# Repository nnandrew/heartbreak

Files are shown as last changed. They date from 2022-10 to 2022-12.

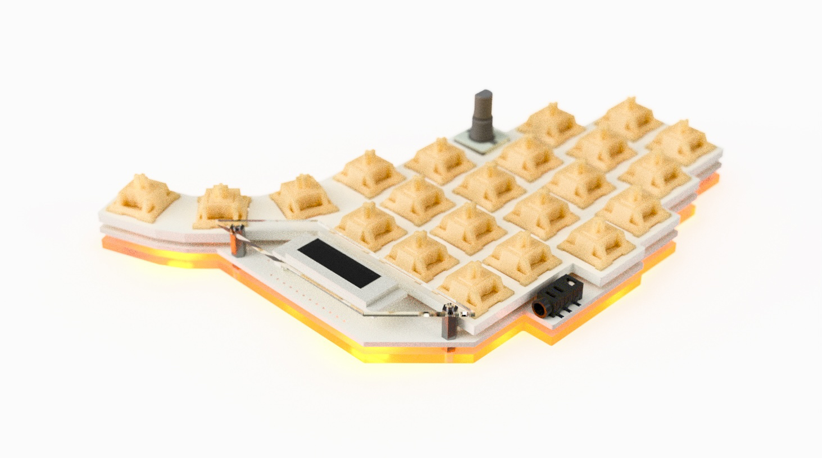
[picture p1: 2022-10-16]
CONCEPTS/underglow_render.jpg

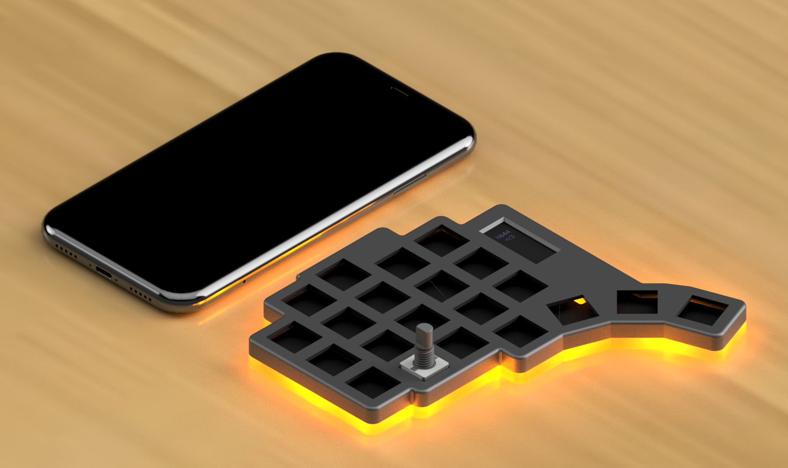
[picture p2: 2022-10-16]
CONCEPTS/aluminum case.png

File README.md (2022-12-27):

# heartbreak
a 40 Key Wireless BLE Split Keyboard with Encoders, LCDs, Haptic Feedback, Fingerprint Reading, Underglow, and a corny theme.

centerGlow
zoom

## Parts
### Required

| Name | Count | Notes |
|:-|:-|:-|
| PCB | 2 | Reversible |
| PCB Coin | 1-2 | fills case hole with a <3 |
| Top Shell | 2  | 3D printed or machined integrated plate |
| Bottom Shell | 2  | Transparent resin print |
| Magnets | 48  | 3x1mm to hold the case together |
| nice!nano v2.0 | 2 | ZMK BLE |
| MCU Sockets | 50-70 | 0627-0-15-15-21-27-10-0 | 
| MCU Pins | 50-70 | 3320-0-00-15-00-00-03-0 |
| Reset Switch | 2 | B3U-3000P-B |
| Power Switch | 2 | PCM12 |
| Battery | 2 | 301230 size |
| Diodes | 42 | SOD-123 SMD |
| Switch Sockets | 40 | Kailh sockets |
| Key Switches | 40 | Only compatible with MX style |
| Keycaps | 40 | All 1u |
| USB C cable | 1 | Data lines required for flashing |

### Optional

| Name | Count | Remarks |
|:-|:-|:-|
| Rubber feet | 8 | reduce sliding |
| nice!view LCD | 2 | low power draw |
| Pimoroni Haptic Buzz | 1 | requires custom firmware |
| Waveshare UART Fingerprint Sensor | 1 | requires custom firmware |
| EC11 Rotary Encoder | 2 | using hardware debouncing |
| 17mm Encoder Knob | 2 | a tight fit |
| Schmitt Trigger | 2 | 74AUP2G14 |
| 10kOhm Resistors | 8 | encoder debounce |
| 0.1uC Capacitors | 4 | for leds and debounce |
| WS2812B | 9 | LEDs for Undergrow |
| SK6812-SIDE | 4 | LEDs for Undergrow |
| P-Channel MOSFET | 2 | SOT-23 to shutoff LEDs |
| 200Ohm Resistors | 2 | current limit for mosfet |
| 200kOhm Resistors | 2 | pulldown for mosfet |
| 0.1uC Capacitors | 26 | for leds and debounce |

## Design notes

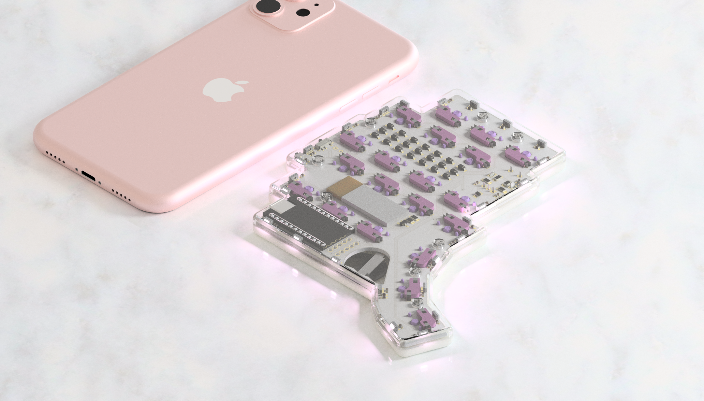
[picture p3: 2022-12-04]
CONCEPTS/showcase v4.png

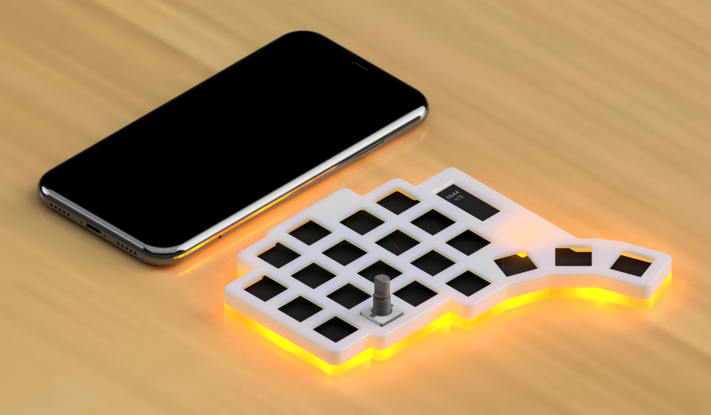
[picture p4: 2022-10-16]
CONCEPTS/plastic case.png

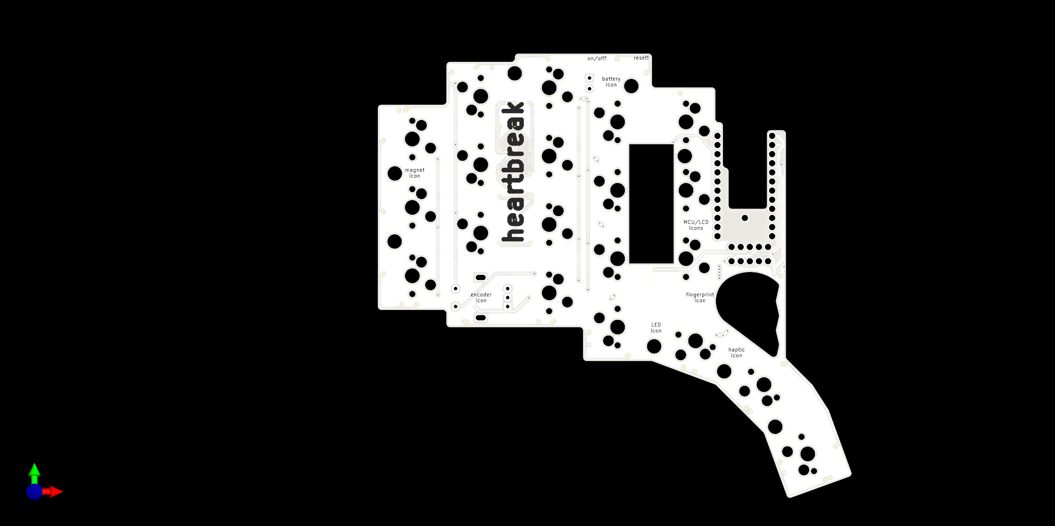
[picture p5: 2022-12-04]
CONCEPTS/frontPCB.png

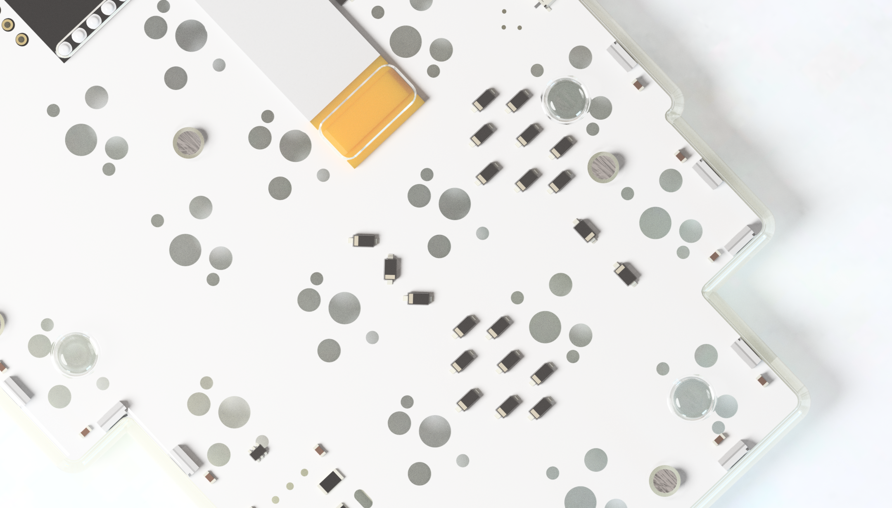
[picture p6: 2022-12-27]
CONCEPTS/heartDiodes.png

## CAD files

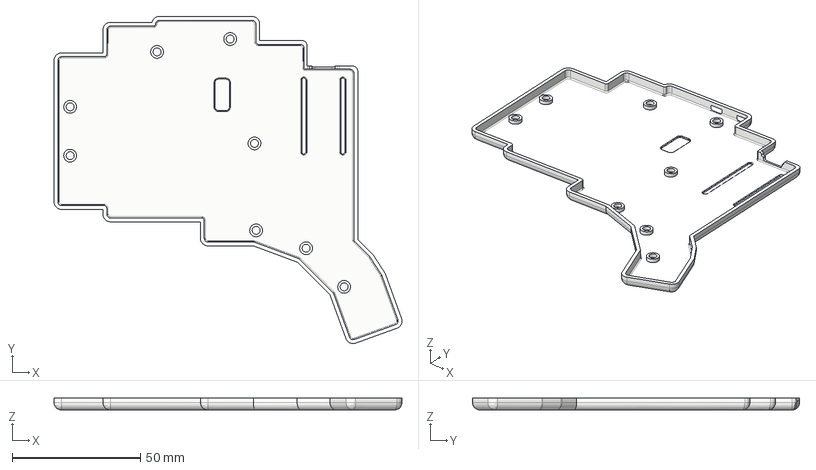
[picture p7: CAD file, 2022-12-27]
3D/production_bottomShell_L.step
135.9 x 127.7 x 4.70 mm

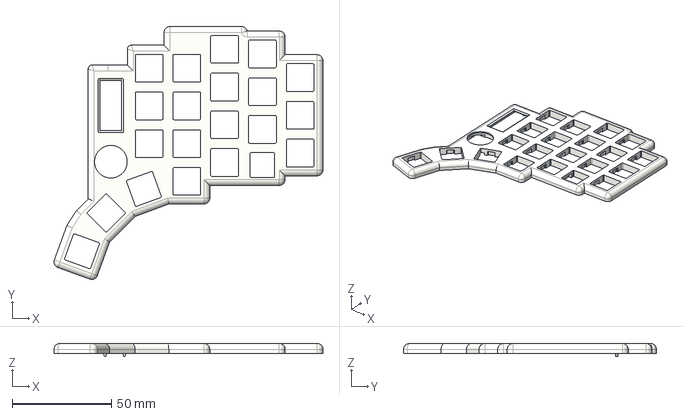
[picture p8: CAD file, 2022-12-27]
3D/production_topShellR.step
135.9 x 127.7 x 6.60 mm

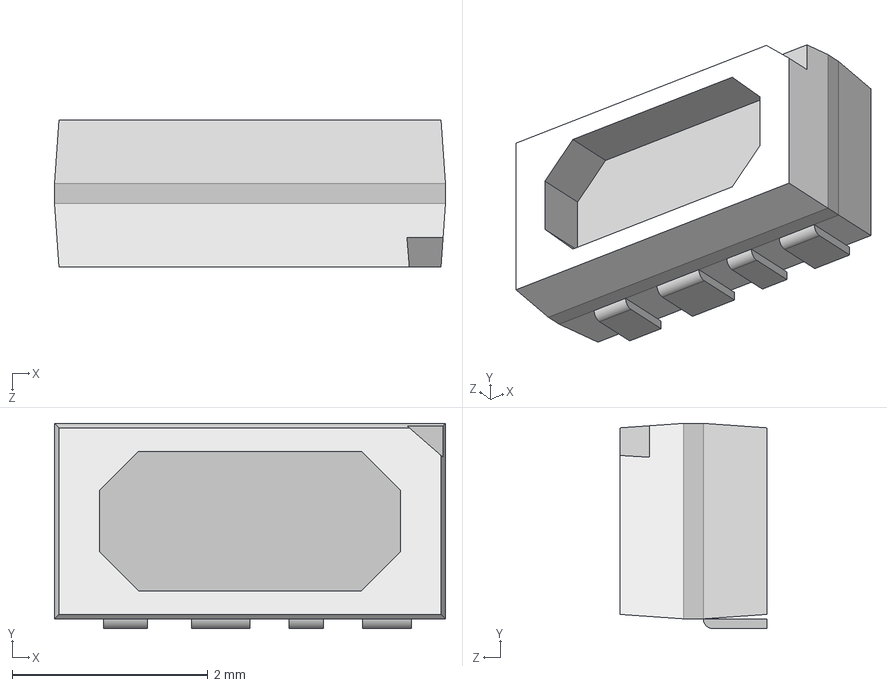
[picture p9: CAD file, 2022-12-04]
3D/SK6812_4020.step
4.00 x 2.10 x 1.50 mm

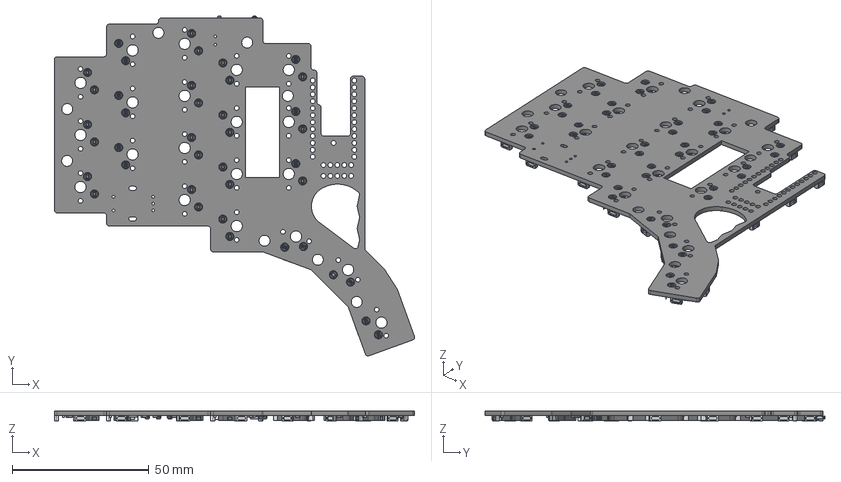
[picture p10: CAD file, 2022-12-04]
3D/pcb.step
131.8 x 124.4 x 3.65 mm
keyboard PCB

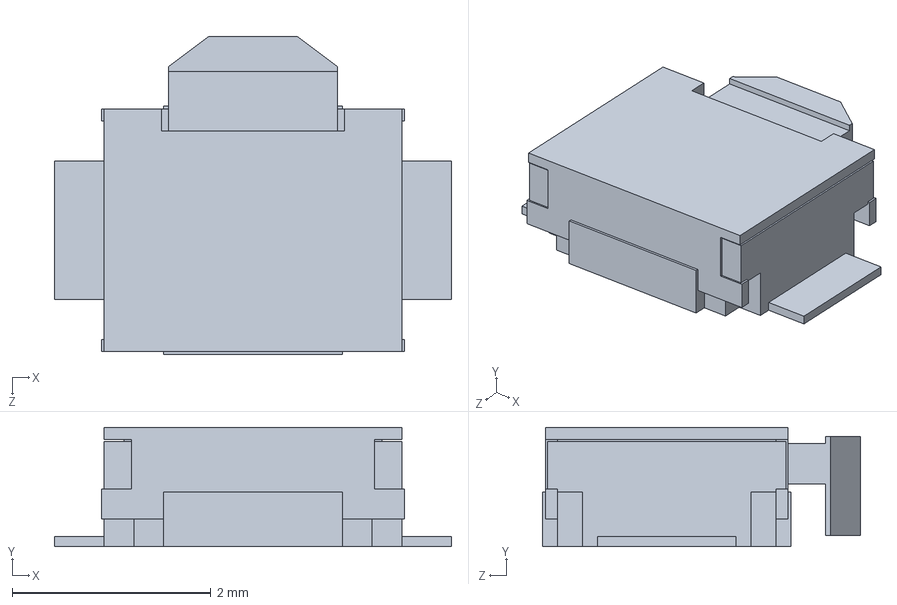
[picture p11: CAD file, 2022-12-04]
3D/B3U_3000P.step
4.00 x 1.20 x 3.20 mm

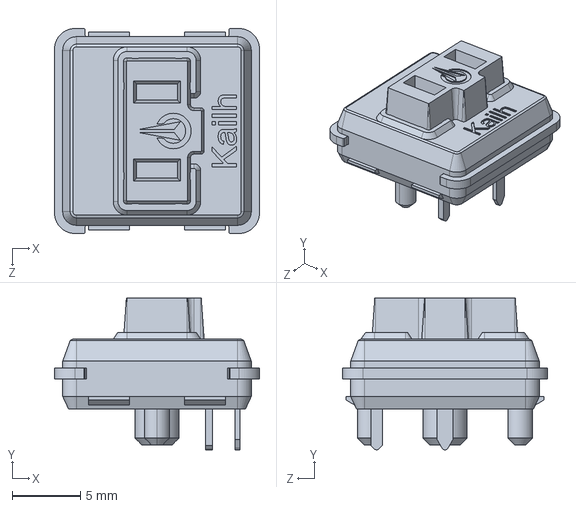
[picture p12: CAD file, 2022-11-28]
3D/Kailh LP Choc Burnt Orange.STEP
15.0 x 11.1 x 15.0 mm

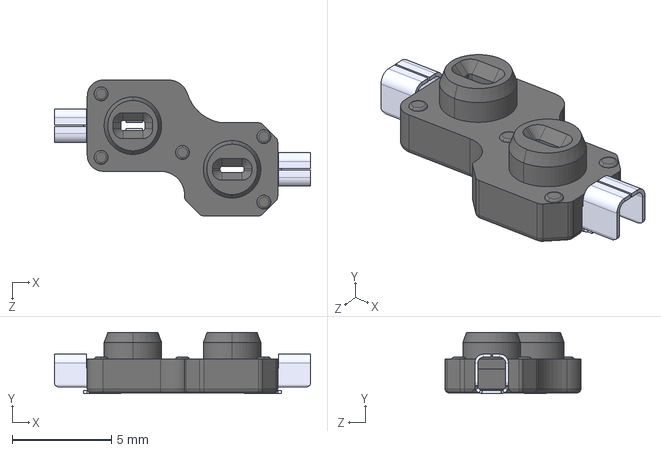
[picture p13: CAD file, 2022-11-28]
3D/PG1350-socket.STEP
12.9 x 3.09 x 6.85 mm
pin x 2
socket

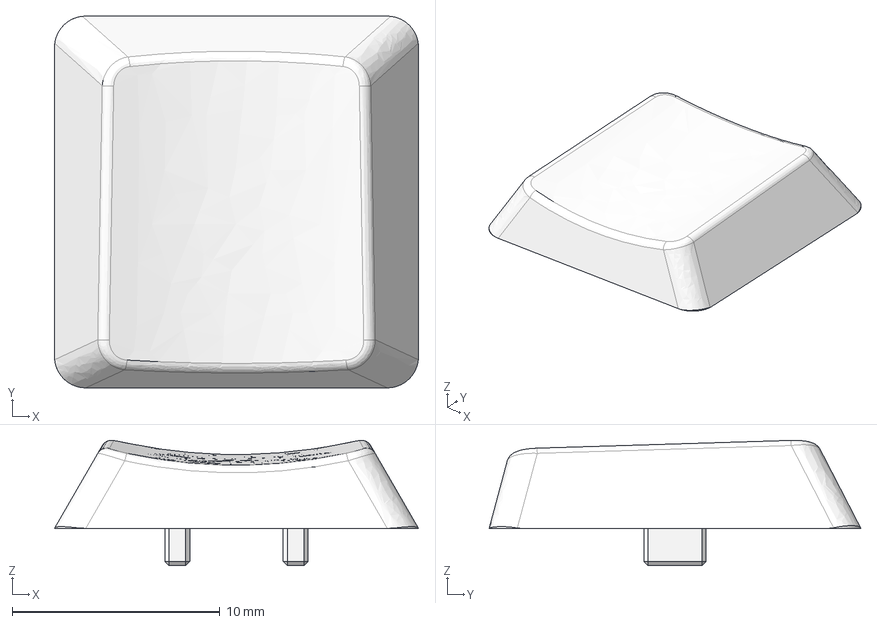
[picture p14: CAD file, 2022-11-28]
3D/Kailh LP Choc PC Keycap.step
17.5 x 17.9 x 6.03 mm

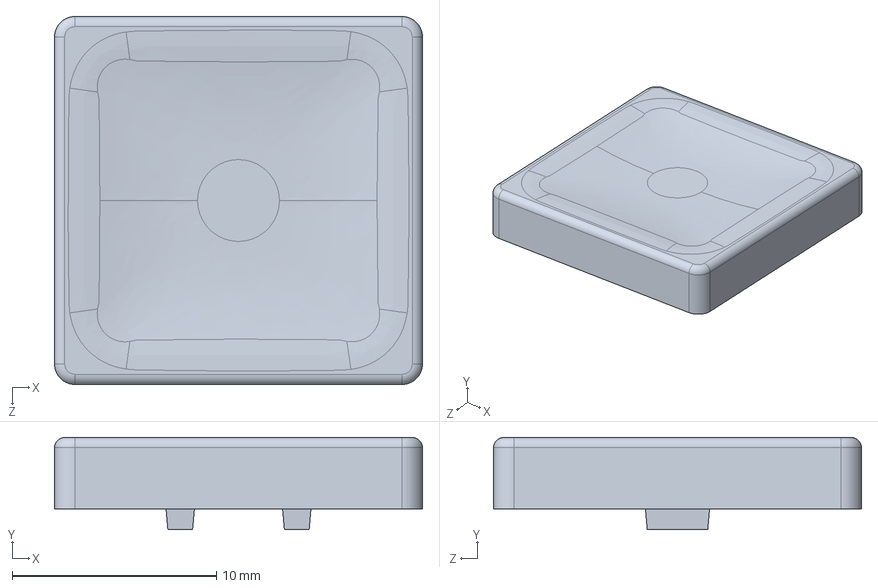
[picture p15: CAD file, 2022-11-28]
3D/1x1.STEP
18.0 x 4.50 x 18.0 mm

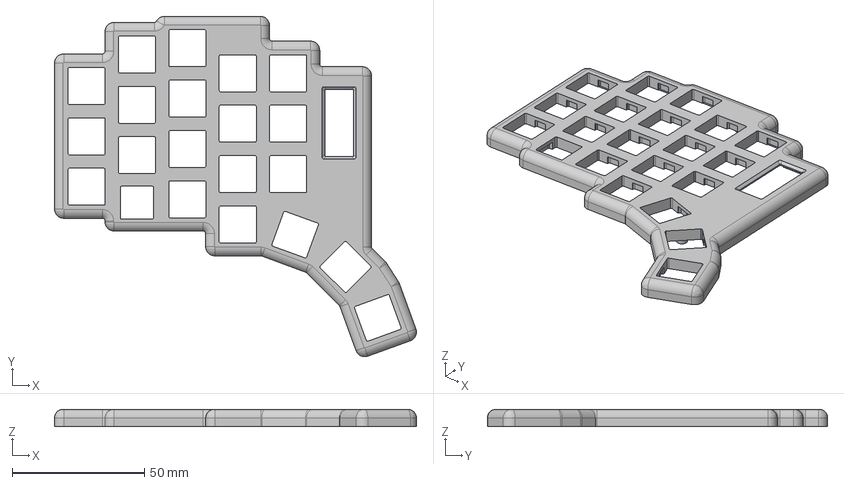
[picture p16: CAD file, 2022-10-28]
3D/Case.step
136.9 x 128.7 x 6.60 mm

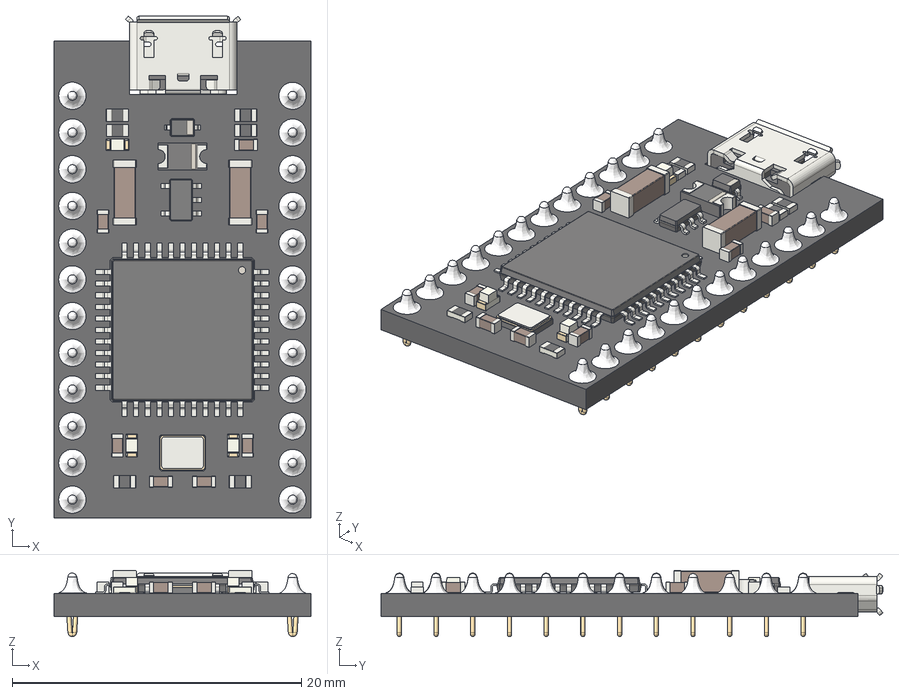
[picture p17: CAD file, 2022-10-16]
3D/nice!nano.step
17.8 x 34.7 x 4.60 mm
TQFP-44_10x10mm_P0.8mm v1
USB_Micro-B_Molex_47346-0001 v1
R_0603 v1 x 6
LED_0603_1608Metric v1 x 3
C_0603_1608Metric v1 x 8
Crystal_SMD_3225-4Pin_3.2x2.5mm v1
D_SOD-323 v1
D_1206_3216Metric v1
TSOT-23-5 v1
C_1806_4516Metric v1 x 2
conthrough v2 x 2

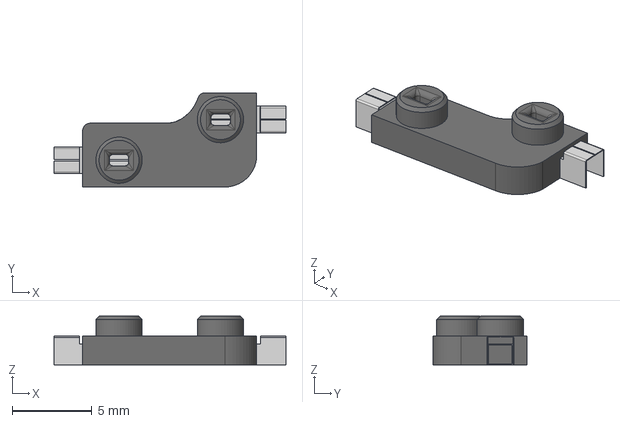
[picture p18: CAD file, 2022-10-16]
3D/Kailh-CherryMX-Socket.step
14.5 x 5.89 x 3.05 mm

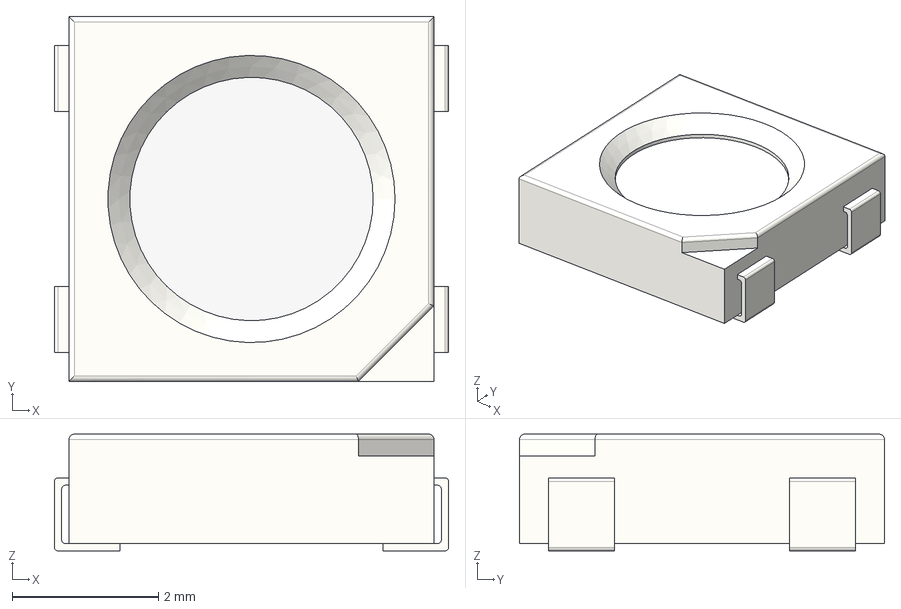
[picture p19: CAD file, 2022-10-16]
3D/WS2812B.step
5.40 x 5.00 x 1.60 mm

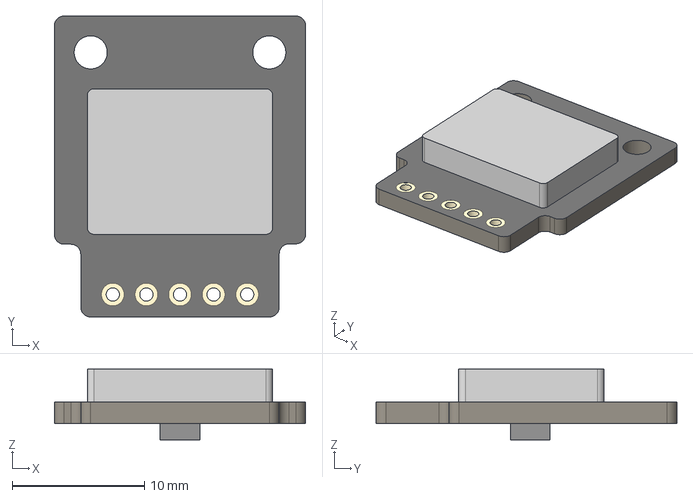
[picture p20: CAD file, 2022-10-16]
3D/pimoroni-haptic-module.step
19.0 x 22.8 x 5.35 mm

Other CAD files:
3D/keyboard-B_Mask.dwg
3D/production_bottomShell_R.step
3D/production_topShellL.step
3D/nice!view.step
3D/CherryMX-Switch.step
3D/DSA_1u.step
3D/ec11.STEP
3D/keyboard-B_Mask.dxf
3D/production_bottomShell_L.stl
3D/production_bottomShell_R.stl

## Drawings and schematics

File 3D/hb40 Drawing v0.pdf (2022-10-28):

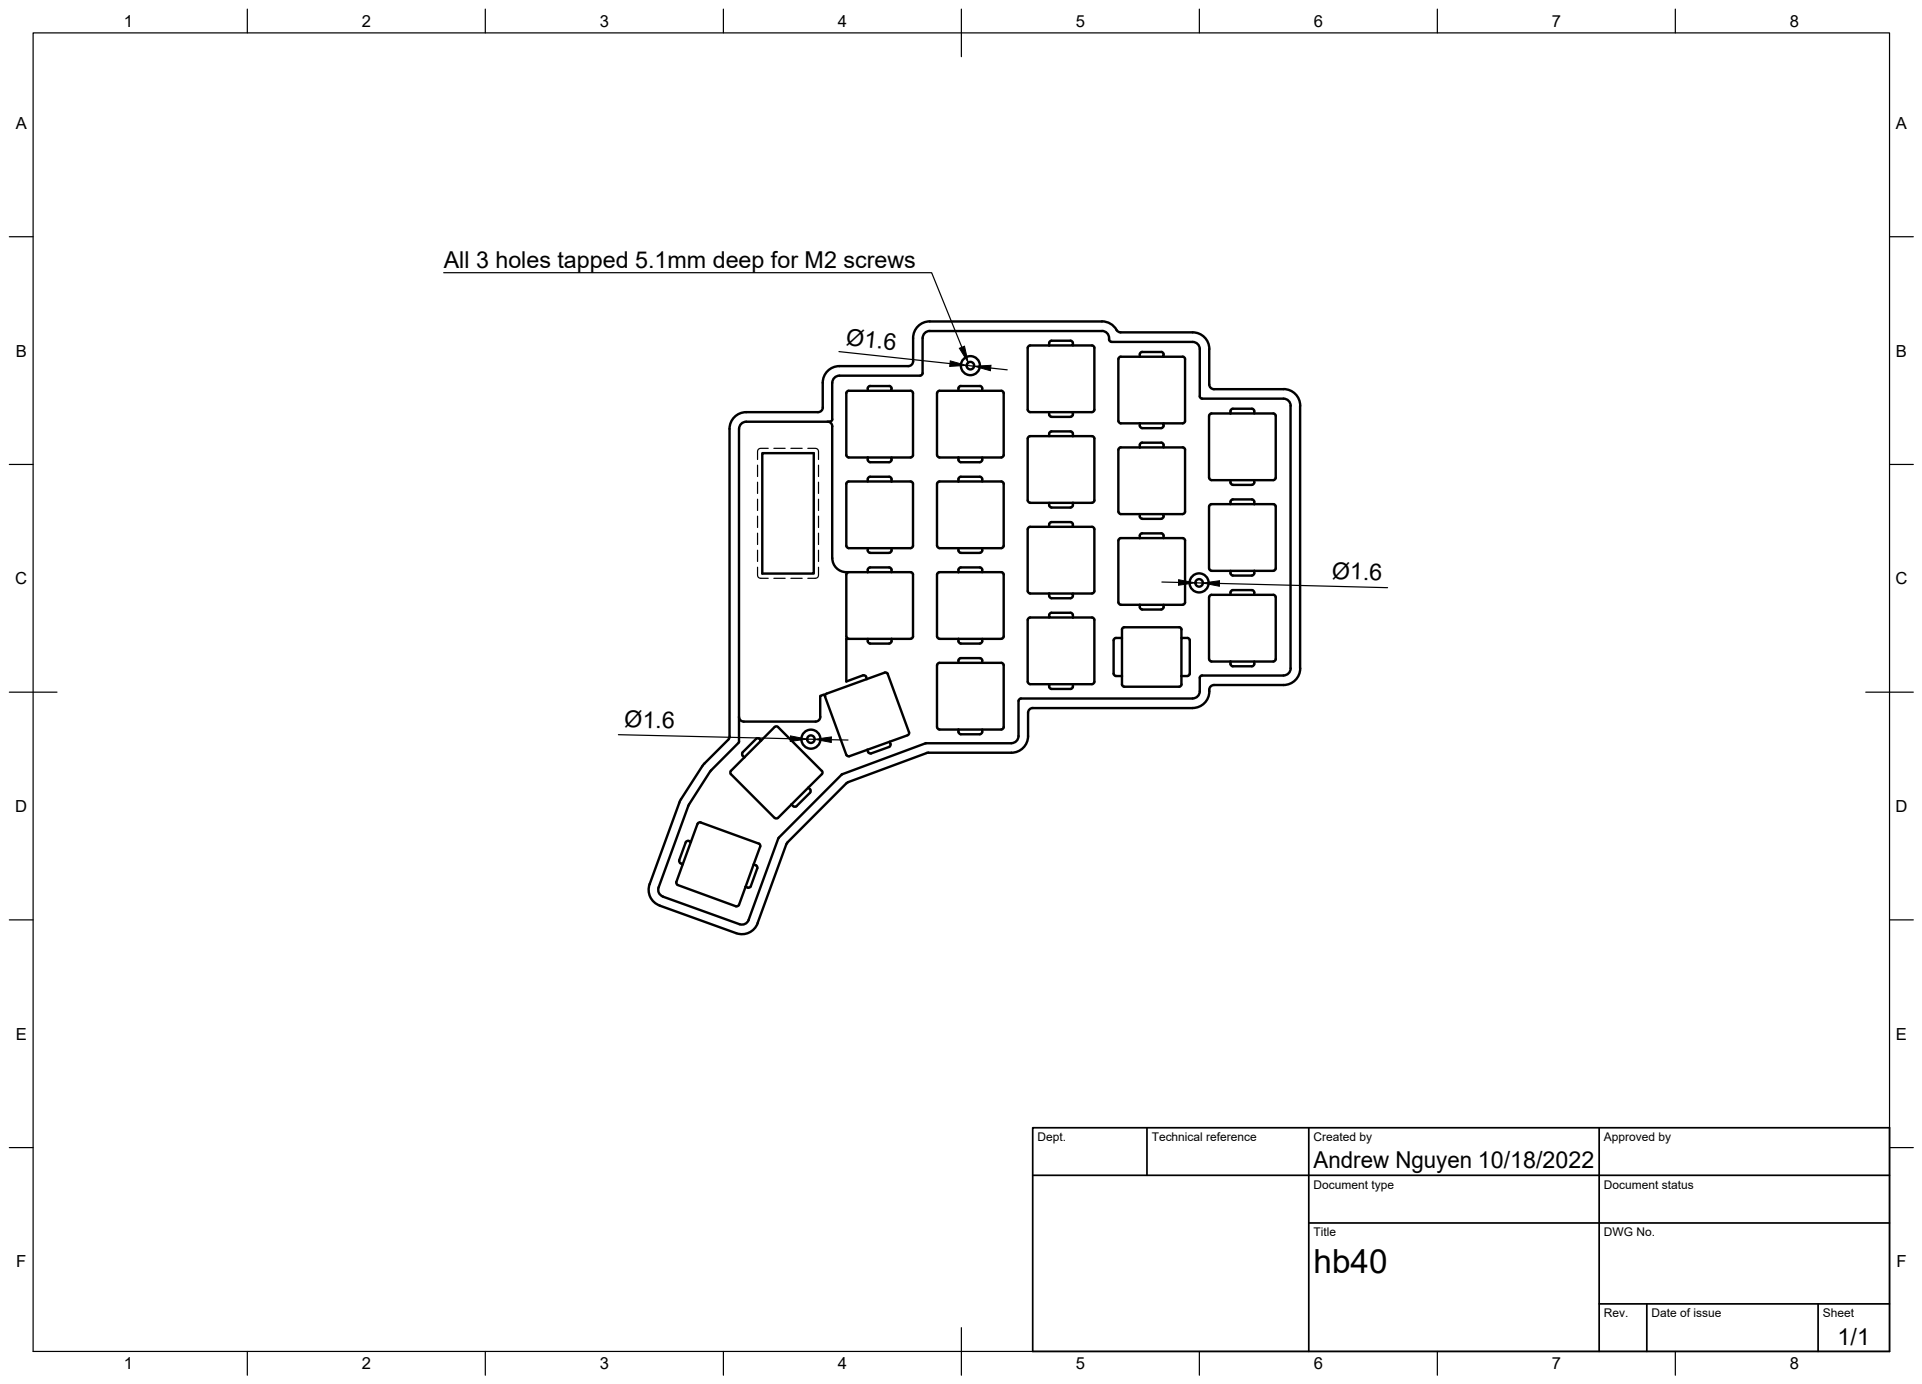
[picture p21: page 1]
Title; DWG No.; Rev.; Date of issue; Sheet

All 3 holes tapped 5.1mm deep for M2 screws

Dept. | Technical reference | Created by Andrew Nguyen 10/18/2022 | Approved by

Document type | Document status

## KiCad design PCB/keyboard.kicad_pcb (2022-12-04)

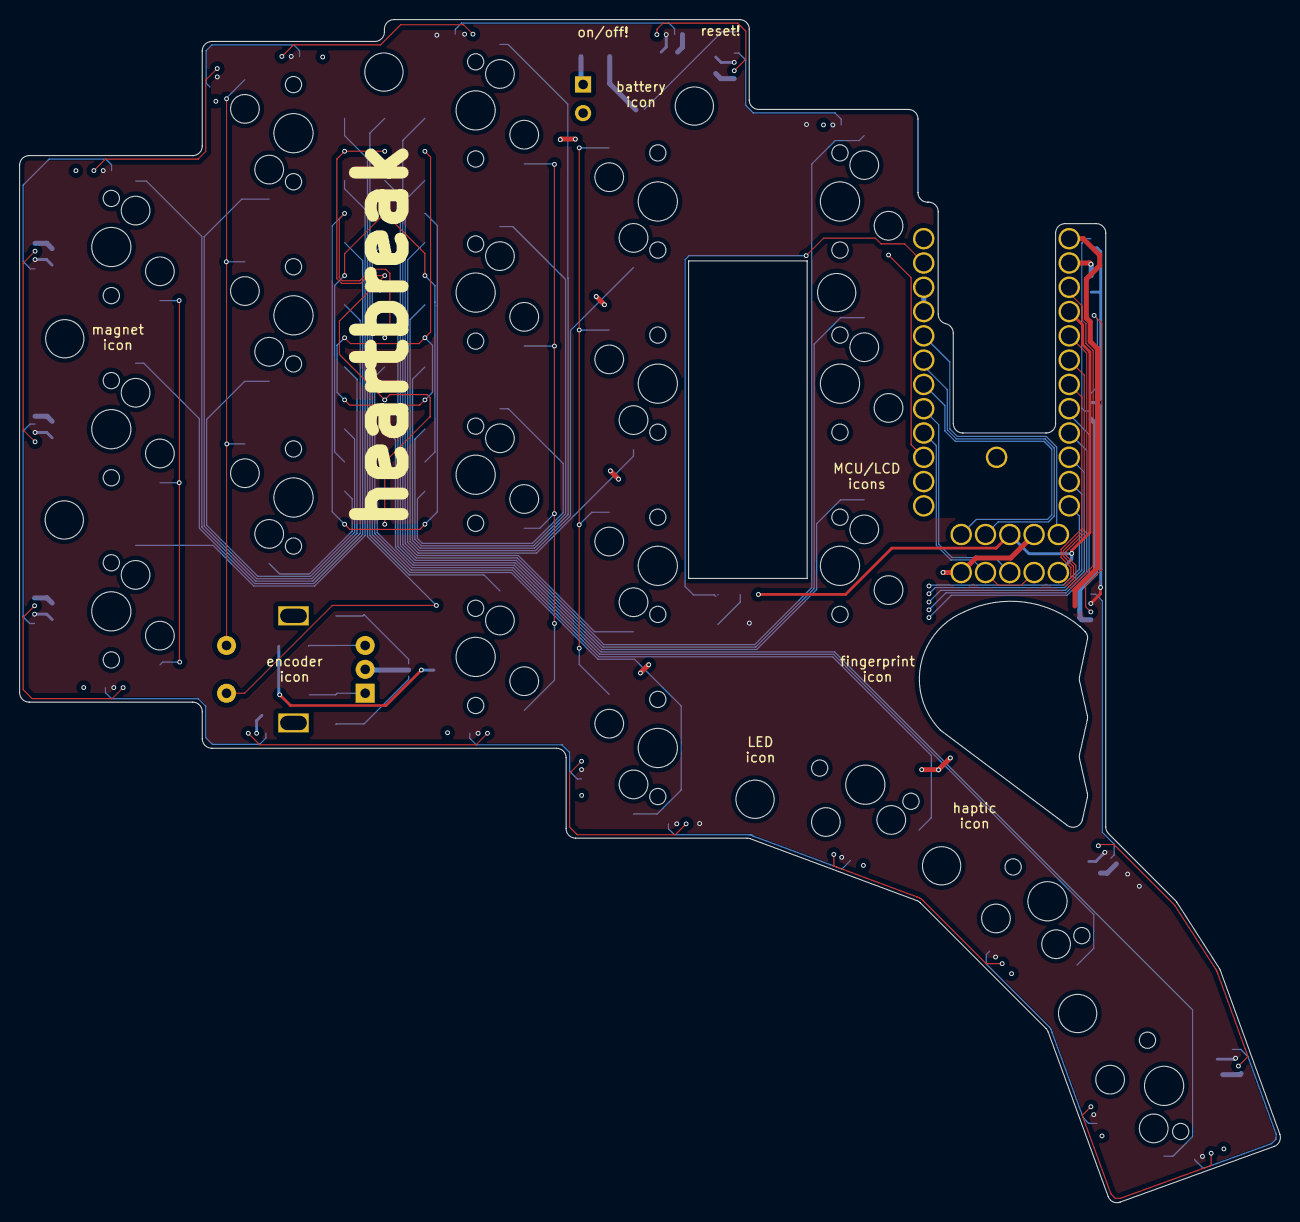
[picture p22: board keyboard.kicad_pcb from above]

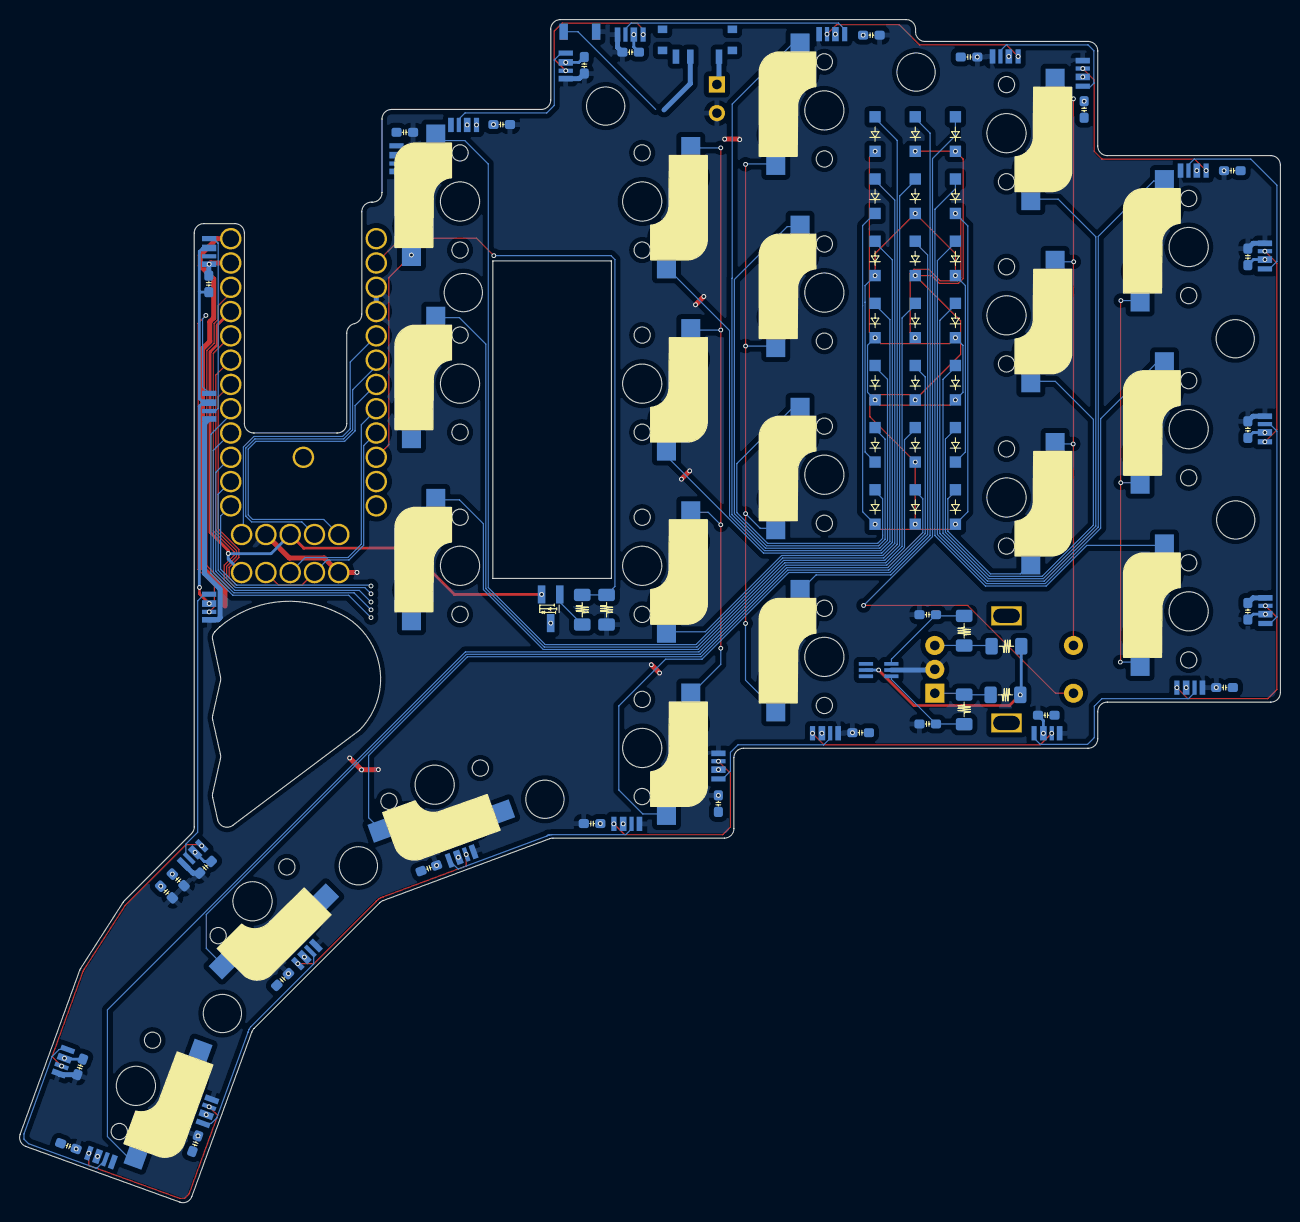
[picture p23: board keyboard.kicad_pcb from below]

Board: 2 copper layers, 131.8 x 123.7 mm, 116 parts (104 on the bottom side), 76 nets.

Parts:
C1, C2, C3, C4, C5, C6, C7, C8, C9, C10, C11, C12, C13, C14, C15, C16, C17, C18, C19, C20, C21, C22, C23, C24, C25, C26, C27: 0.1u; SMD_Cap_0603
D1, D2, D3, D4, D5, D6, D7, D8, D9, D10, D11, D12, D13, D14, D15, D16, D17, D18, D19, D20, D21: SMD_SOD123
H1, H2, H3, H4, H5, H6, H7, H8: MountingHole; MountingHole_4mm
J1: Conn_01x05; Pimoroni Haptic Buzz
J2: Conn_01x02; TH_BatteryConn
LCD1: nice!view
LED1, LED2, LED3, LED4, LED5, LED6, LED7, LED8, LED9, LED10, LED11, LED12, LED13, LED14, LED15, LED16, LED17, LED18, LED19, LED20, LED21, LED22, LED23, LED24, LED25: SK6812; SK6812-SIDE
Q1: Q_PMOS_GSD; SMD_P_MOSFET_SOT-23
R1, R2, R3, R4: 10k; SMD_Res_1206
R5: 200; SMD_Res_1206
R6: 200k; SMD_Res_1206
SW1, SW2, SW3, SW4, SW5, SW6, SW7, SW8, SW9, SW10, SW11, SW12, SW13, SW14, SW15, SW17, SW18, SW19, SW20, SW21: MX; SMD_CherryMX_MidHeight_HotSwap
SW16: RotaryEncoder_Switch; EC11
SW43: SW_DPDT_x2; SMD_SW_SPDT_PCM12
SW44: SW_PUSH; SMD_SW_SPST_B3U-3000P-B
U1: ProMicro_r; nice!nano
U2: 74AUP2G14; SMD_74AUP2G14_SOT-363

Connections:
+3V3: J1.1, LCD1.3 (VCC), Q1.2 (S), R1.1, R2.1, U1.21 (3.3V), U2.5 (VCC)
/RAW_BAT: J2.1, SW43.1 (A)
ARGB: LED1.1 (DIN), U1.1 (P0.06/H)
CS: LCD1.5 (CS), U1.5 (P0.17/H)
GND: C1.2, C2.2, C3.2, C4.2, C5.2, C6.1, C7.1, C8.1, C9.1, C10.1, C11.2, C12.2, C13.2, C14.2, C15.2, C16.1, C17.1, C18.1, C19.1, C20.1, C21.2, C22.2, C23.2, C24.2, C26.2, C27.2, J1.5, J2.2, LCD1.4 (GND), LED1.4 (VSS), LED2.4 (VSS), LED3.4 (VSS), LED4.4 (VSS), LED5.4 (VSS), LED6.4 (VSS), LED7.4 (VSS), LED8.4 (VSS), LED9.4 (VSS), LED10.4 (VSS), LED11.4 (VSS), LED12.4 (VSS), LED13.4 (VSS), LED14.4 (VSS), LED15.4 (VSS), LED16.4 (VSS), LED17.4 (VSS), LED18.4 (VSS), LED19.4 (VSS), LED20.4 (VSS), LED21.4 (VSS), LED22.4 (VSS), LED23.4 (VSS), LED24.4 (VSS), R6.2, SW16.C, SW44.2, U1.3 (GND), U1.4 (GND), U2.2 (GND)
GND1: C25.2, LED25.4 (VSS), U1.23 (GND)
LED: R5.1, R6.1, U1.2 (P0.08/H)
LED_VCC: C1.1, C2.1, C3.1, C4.1, C5.1, C6.2, C7.2, C8.2, C9.2, C10.2, C11.1, C12.1, C13.1, C14.1, C15.1, C16.2, C17.2, C18.2, C19.2, C20.2, C21.1, C22.1, C23.1, C24.1, C25.1, LED1.2 (VDD), LED2.2 (VDD), LED3.2 (VDD), LED4.2 (VDD), LED5.2 (VDD), LED6.2 (VDD), LED7.2 (VDD), LED8.2 (VDD), LED9.2 (VDD), LED10.2 (VDD), LED11.2 (VDD), LED12.2 (VDD), LED13.2 (VDD), LED14.2 (VDD), LED15.2 (VDD), LED16.2 (VDD), LED17.2 (VDD), LED18.2 (VDD), LED19.2 (VDD), LED20.2 (VDD), LED21.2 (VDD), LED22.2 (VDD), LED23.2 (VDD), LED24.2 (VDD), LED25.2 (VDD), Q1.3 (D)
MOSI: LCD1.1 (MOSI), U1.7 (P0.22/H)
unnamed: R3.2, U2.1
unnamed: R4.2, U2.3
unnamed: D1.2 (A), SW1.2 (ROW)
unnamed: D2.2 (A), SW2.2 (ROW)
unnamed: D3.2 (A), SW3.2 (ROW)
unnamed: D4.2 (A), SW4.2 (ROW)
unnamed: D5.2 (A), SW5.2 (ROW)
unnamed: D6.2 (A), SW6.2 (ROW)
unnamed: D7.2 (A), SW7.2 (ROW)
unnamed: D8.2 (A), SW8.2 (ROW)
unnamed: D9.2 (A), SW9.2 (ROW)
unnamed: D10.2 (A), SW10.2 (ROW)
unnamed: D11.2 (A), SW11.2 (ROW)
unnamed: D12.2 (A), SW12.2 (ROW)
unnamed: D13.2 (A), SW13.2 (ROW)
unnamed: D14.2 (A), SW14.2 (ROW)
unnamed: D15.2 (A), SW15.2 (ROW)
unnamed: D17.2 (A), SW17.2 (ROW)
unnamed: D18.2 (A), SW18.2 (ROW)
unnamed: D19.2 (A), SW19.2 (ROW)
unnamed: D20.2 (A), SW20.2 (ROW)
unnamed: D21.2 (A), SW21.2 (ROW)
unnamed: LED1.3 (DOUT), LED2.1 (DIN)
unnamed: LED2.3 (DOUT), LED3.1 (DIN)
unnamed: LED3.3 (DOUT), LED4.1 (DIN)
unnamed: LED4.3 (DOUT), LED5.1 (DIN)
unnamed: LED5.3 (DOUT), LED6.1 (DIN)
unnamed: LED6.3 (DOUT), LED7.1 (DIN)
unnamed: LED7.3 (DOUT), LED8.1 (DIN)
unnamed: LED8.3 (DOUT), LED9.1 (DIN)
unnamed: LED9.3 (DOUT), LED10.1 (DIN)
unnamed: LED10.3 (DOUT), LED11.1 (DIN)
unnamed: LED11.3 (DOUT), LED12.1 (DIN)
unnamed: LED12.3 (DOUT), LED13.1 (DIN)
unnamed: LED13.3 (DOUT), LED14.1 (DIN)
unnamed: LED14.3 (DOUT), LED15.1 (DIN)
unnamed: LED16.3 (DOUT), LED17.1 (DIN)
unnamed: LED17.3 (DOUT), LED18.1 (DIN)
unnamed: LED18.3 (DOUT), LED19.1 (DIN)
unnamed: LED19.3 (DOUT), LED20.1 (DIN)
unnamed: LED20.3 (DOUT), LED21.1 (DIN)
unnamed: LED21.3 (DOUT), LED22.1 (DIN)
unnamed: LED22.3 (DOUT), LED23.1 (DIN)
unnamed: LED23.3 (DOUT), LED24.1 (DIN)
unnamed: LED24.3 (DOUT), LED25.1 (DIN)
unnamed: Q1.1 (G), R5.2
unnamed: R1.2, R3.1, SW16.A
unnamed: R2.2, R4.1, SW16.B
RAW: SW43.2 (B), U1.24 (BAT+)
RESET: SW44.1, U1.22 (RESET)
R_LED_VCC: C26.1, C27.1
SCK: LCD1.2 (SCK), U1.6 (P0.20/H)
SCL/RX: J1.3, U1.8 (P0.24/H)
SDA/TX: J1.2, J1.4, U1.9 (P1.00/H)
col0: SW1.1 (COL), SW6.1 (COL), SW11.1 (COL), SW21.1 (COL), U1.16 (P1.13/L)
col1: SW2.1 (COL), SW7.1 (COL), SW12.1 (COL), SW16.S1, U1.15 (P1.11/L)
col2: SW3.1 (COL), SW8.1 (COL), SW13.1 (COL), SW17.1 (COL), U1.14 (P0.10/L)
col3: SW4.1 (COL), SW9.1 (COL), SW14.1 (COL), SW18.1 (COL), U1.13 (P0.09/L)
col4: SW5.1 (COL), SW10.1 (COL), SW15.1 (COL), SW19.1 (COL), U1.10 (P0.11/H)
col5: SW20.1 (COL), U1.27 (P1.07/L)
rotA: U1.12 (P1.06/L), U2.6
rotB: U1.11 (P1.04/L), U2.4
rotS2: D16.2 (A), SW16.S2
row0: D1.1 (K), D2.1 (K), D3.1 (K), D4.1 (K), D5.1 (K), U1.20 (P0.31/L)
row1: D6.1 (K), D7.1 (K), D8.1 (K), D9.1 (K), D10.1 (K), U1.19 (P0.29/L)
row2: D11.1 (K), D12.1 (K), D13.1 (K), D14.1 (K), D15.1 (K), U1.18 (P0.02/L)
row3: D16.1 (K), D17.1 (K), D18.1 (K), D19.1 (K), D20.1 (K), D21.1 (K), U1.17 (P1.15/L)

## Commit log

2022-10-02 folder structure
    [128x32-OLED.SLDPRT, ImageToStl.com_mechswitch.stl, JackPJ313D.STEP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]
2022-10-05 preliminary routing
    [keyboard.kicad_pcb, keyboard.kicad_sch]
2022-10-10 3d assets + bad routing
    [128x32-OLED.SLDPRT, CherryMX-Switch.step, Choc-Socket.step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]
2022-10-14 wired compatible/breakaway
    [keyboard.kicad_pcb, keyboard.kicad_sch]
2022-10-16 curvy traces
    [keyboard.kicad_pcb, keyboard.kicad_sch]
2022-10-16 housekeeping
    deleted unused files
    [Choc-Socket.step, keyboard.kicad_sch, keyboard.sch]
2022-10-28 working 44
    [Case.step, keyboard.kicad_pcb, keyboard.kicad_sch]
2022-11-28 reversible WIP
    [1.25x1.STEP, 1.5x1.STEP, 1.75x1.STEP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]
2024-05-07 cleaned directory + led fix
